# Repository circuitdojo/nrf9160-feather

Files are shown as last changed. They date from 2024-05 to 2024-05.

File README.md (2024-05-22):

# Circuit Dojo - nRF9160 Feather Hardware Files

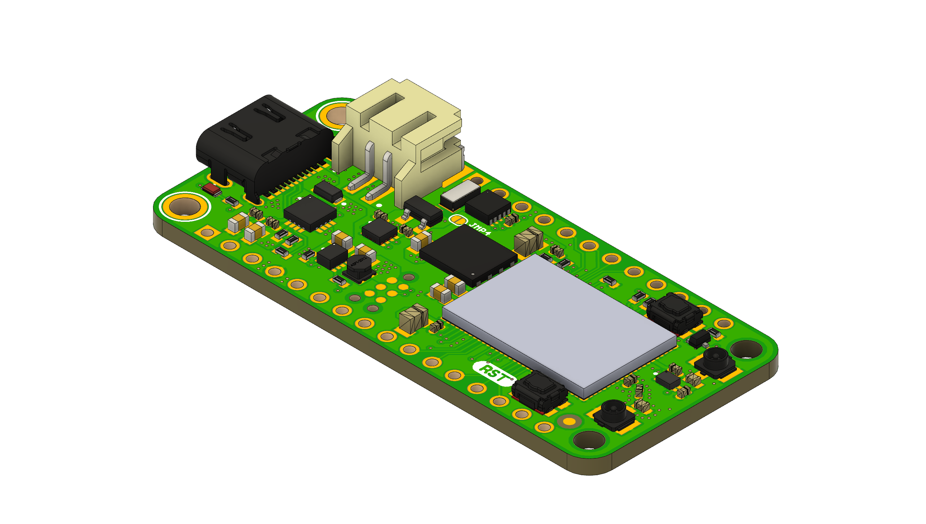
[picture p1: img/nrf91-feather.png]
nRF9160 Feather


## Purchase

Considering supporting the project and purchasing a nRF9160 Feather at the following locations:

1. [The Circuit Dojo Official Store](https://www.circuitdojo.com/products/nrf9160-feather)
2. [Digikey](https://www.digikey.com/en/products/detail/circuit-dojo/PASSY-NRF9160-FEATHER/13668137)

## Code

All code for this board can be [found here.](https://github.com/circuitdojo/nrf9160-feather-examples-and-drivers/tree/v1.9.x)

## Documentation

[Documentation is available here.](https://docs.circuitdojo.com)

## License

Hardware released under the CERN Open Hardware Licence Version 2 - Weakly Reciprocal. See **LICENSE.txt** for more info.

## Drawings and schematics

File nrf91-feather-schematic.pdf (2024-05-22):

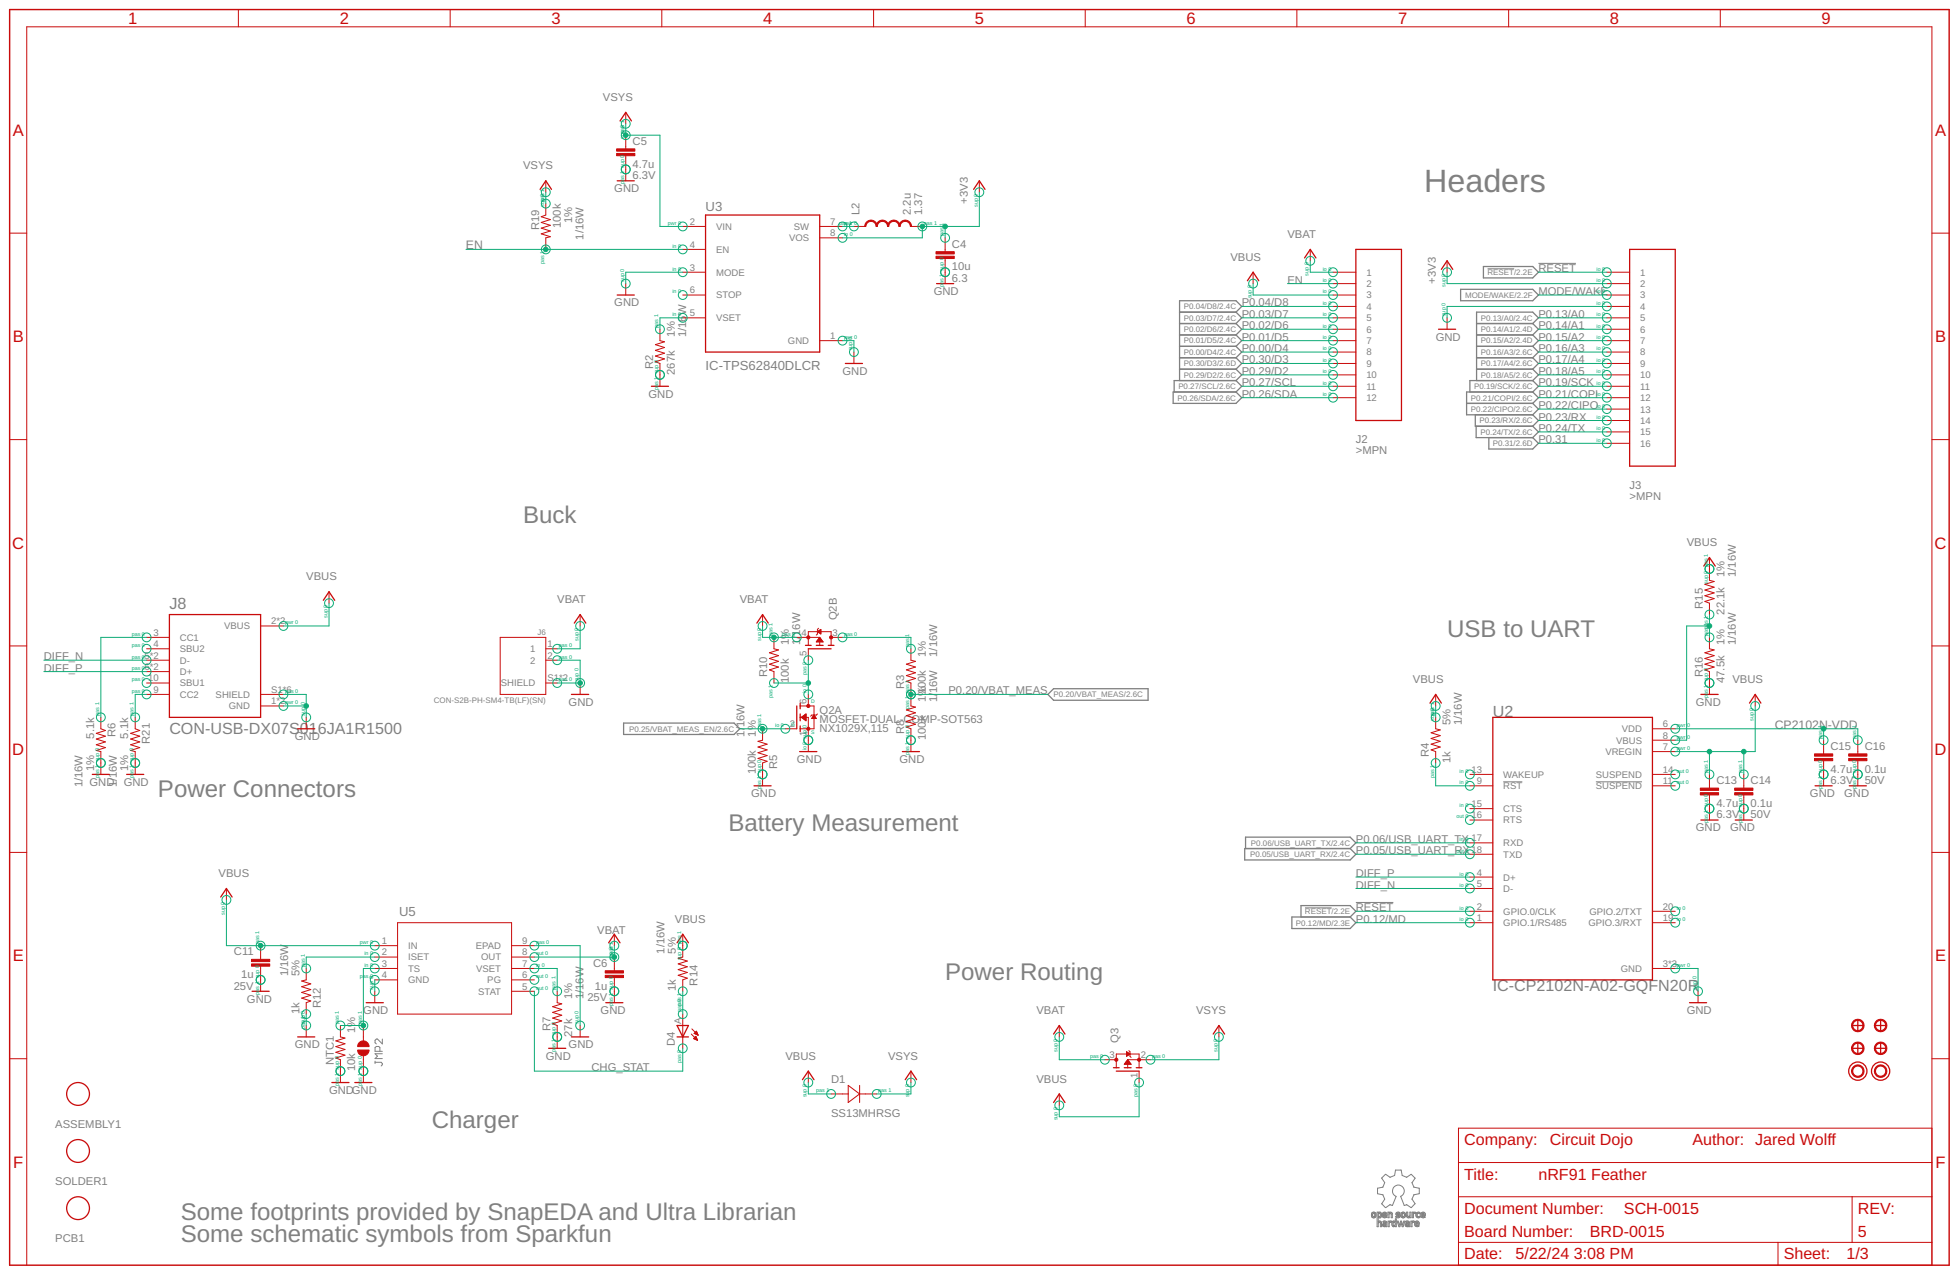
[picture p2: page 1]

sup 0
MODE/WAKE/2.2F MODE/WAKE

sup 0 pas 1 pas 1 pas 1 pas 1 sup 0

pas 1 pas 1 pas 1 pas 1 sup 0

in 0 | 8 EPAD 7 OUT out 0

pas 1 pas 1 pas 0 pas 0

in 0 | 6 VSET in 0

Some footprints provided by SnapEDA and Ultra Librarian
Some schematic symbols from Sparkfun

SCH-0015

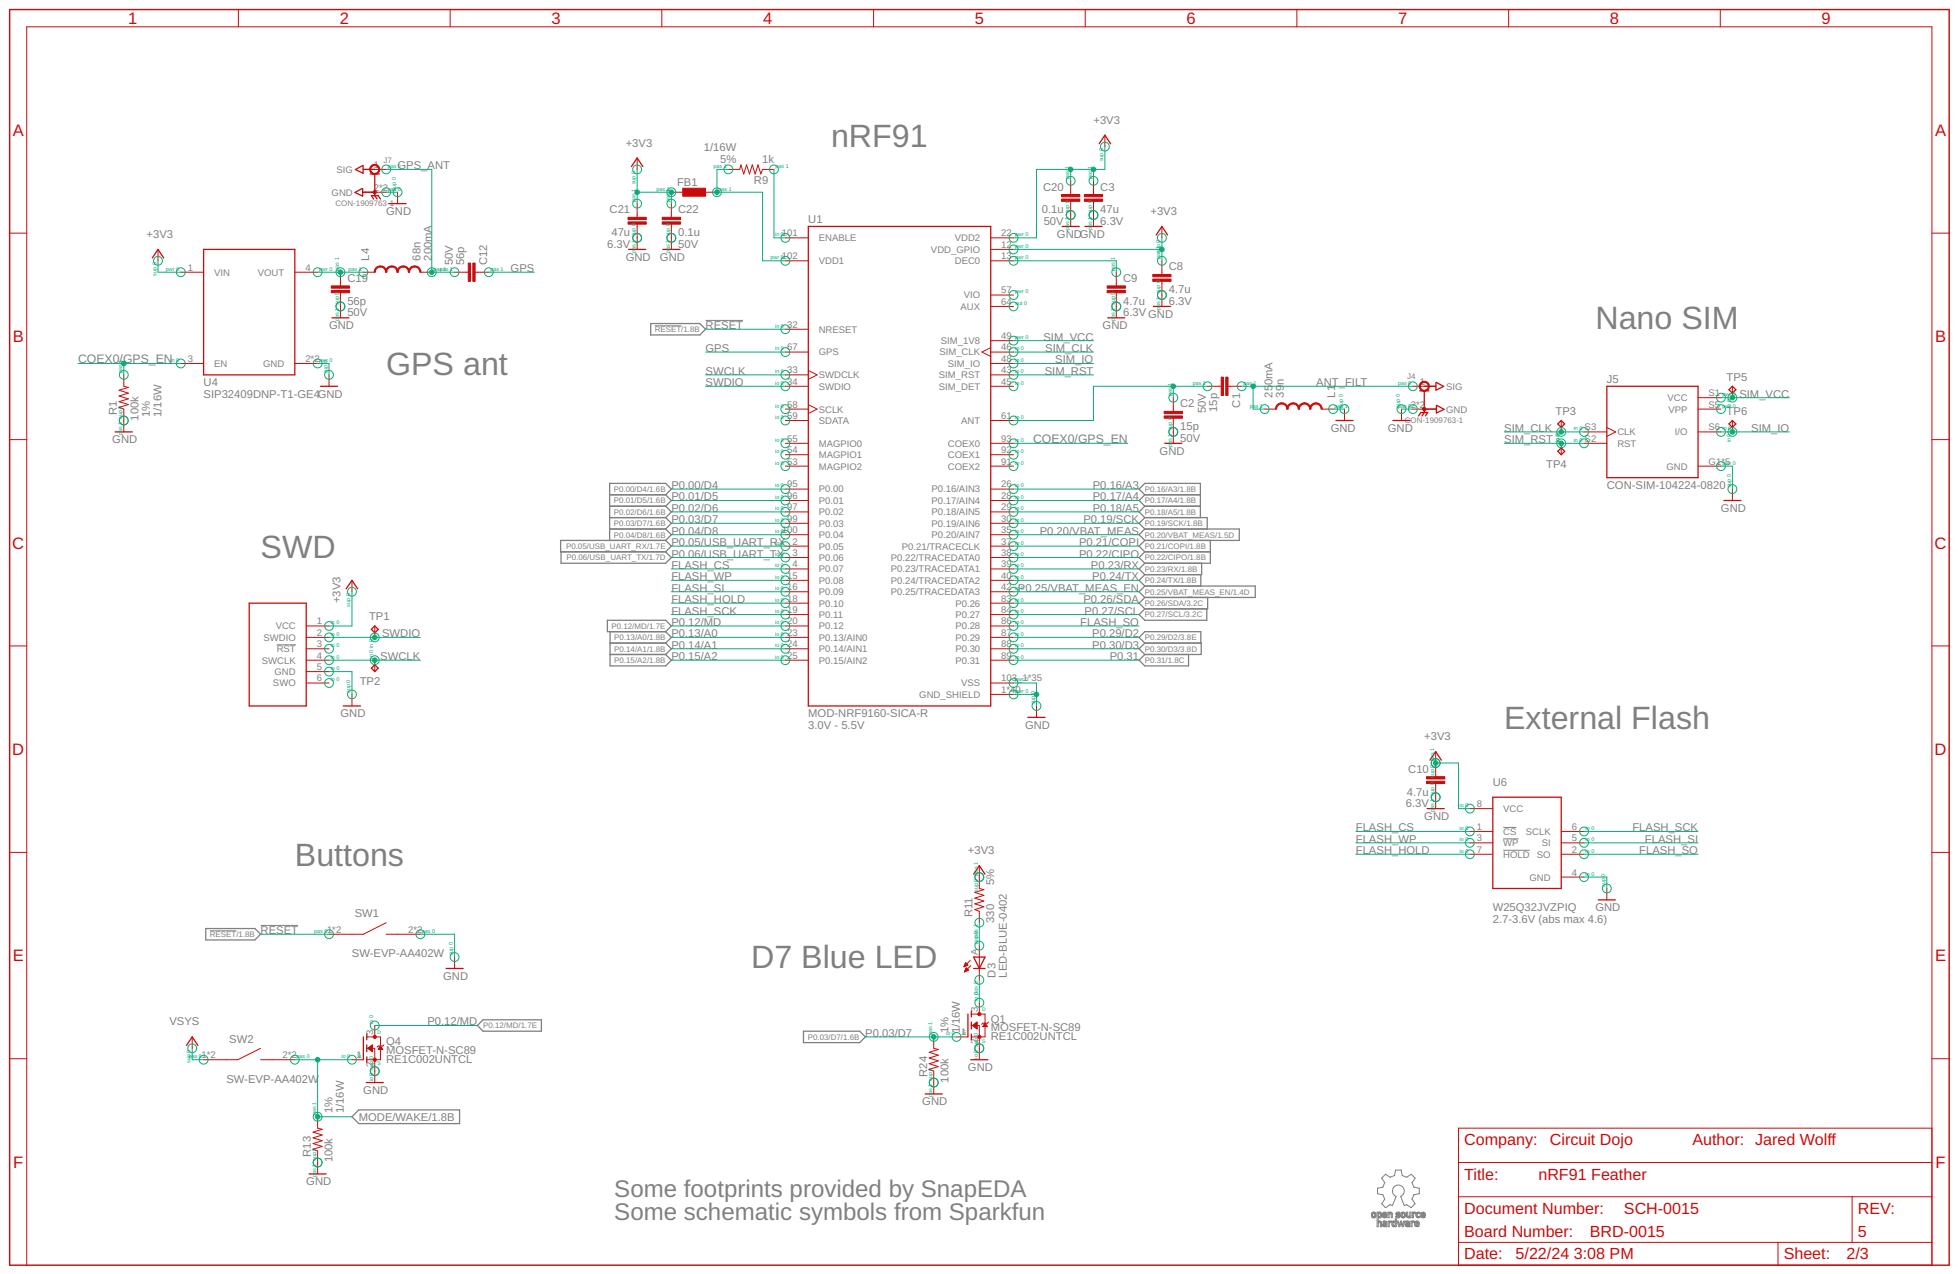
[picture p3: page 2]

sup 0 pas 1 pas 1 sup 0

Some footprints provided by SnapEDA
Some schematic symbols from Sparkfun

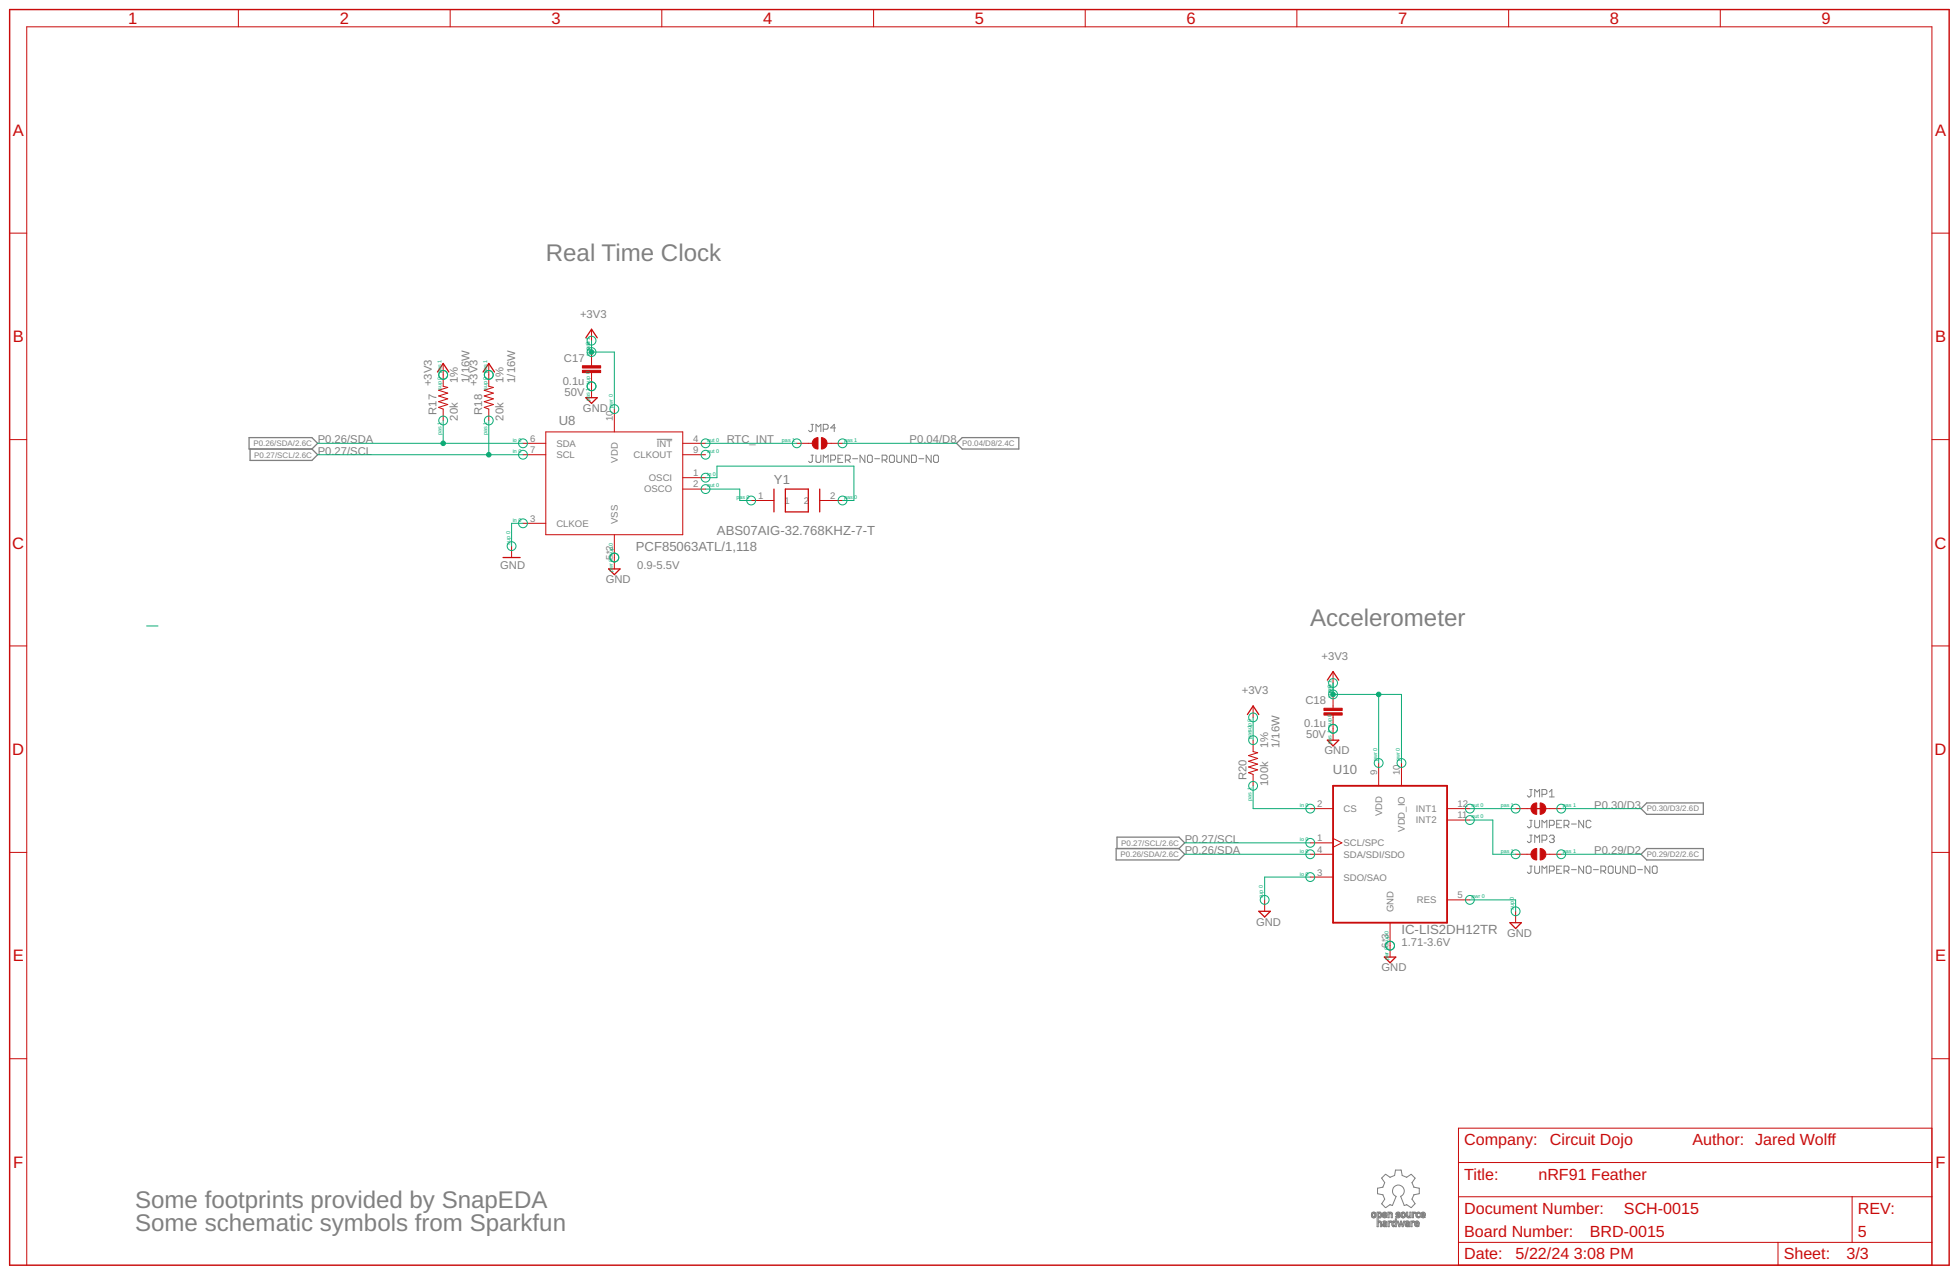
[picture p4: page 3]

pas 1 pas 1 sup 0 sup 0

Some footprints provided by SnapEDA
Some schematic symbols from Sparkfun

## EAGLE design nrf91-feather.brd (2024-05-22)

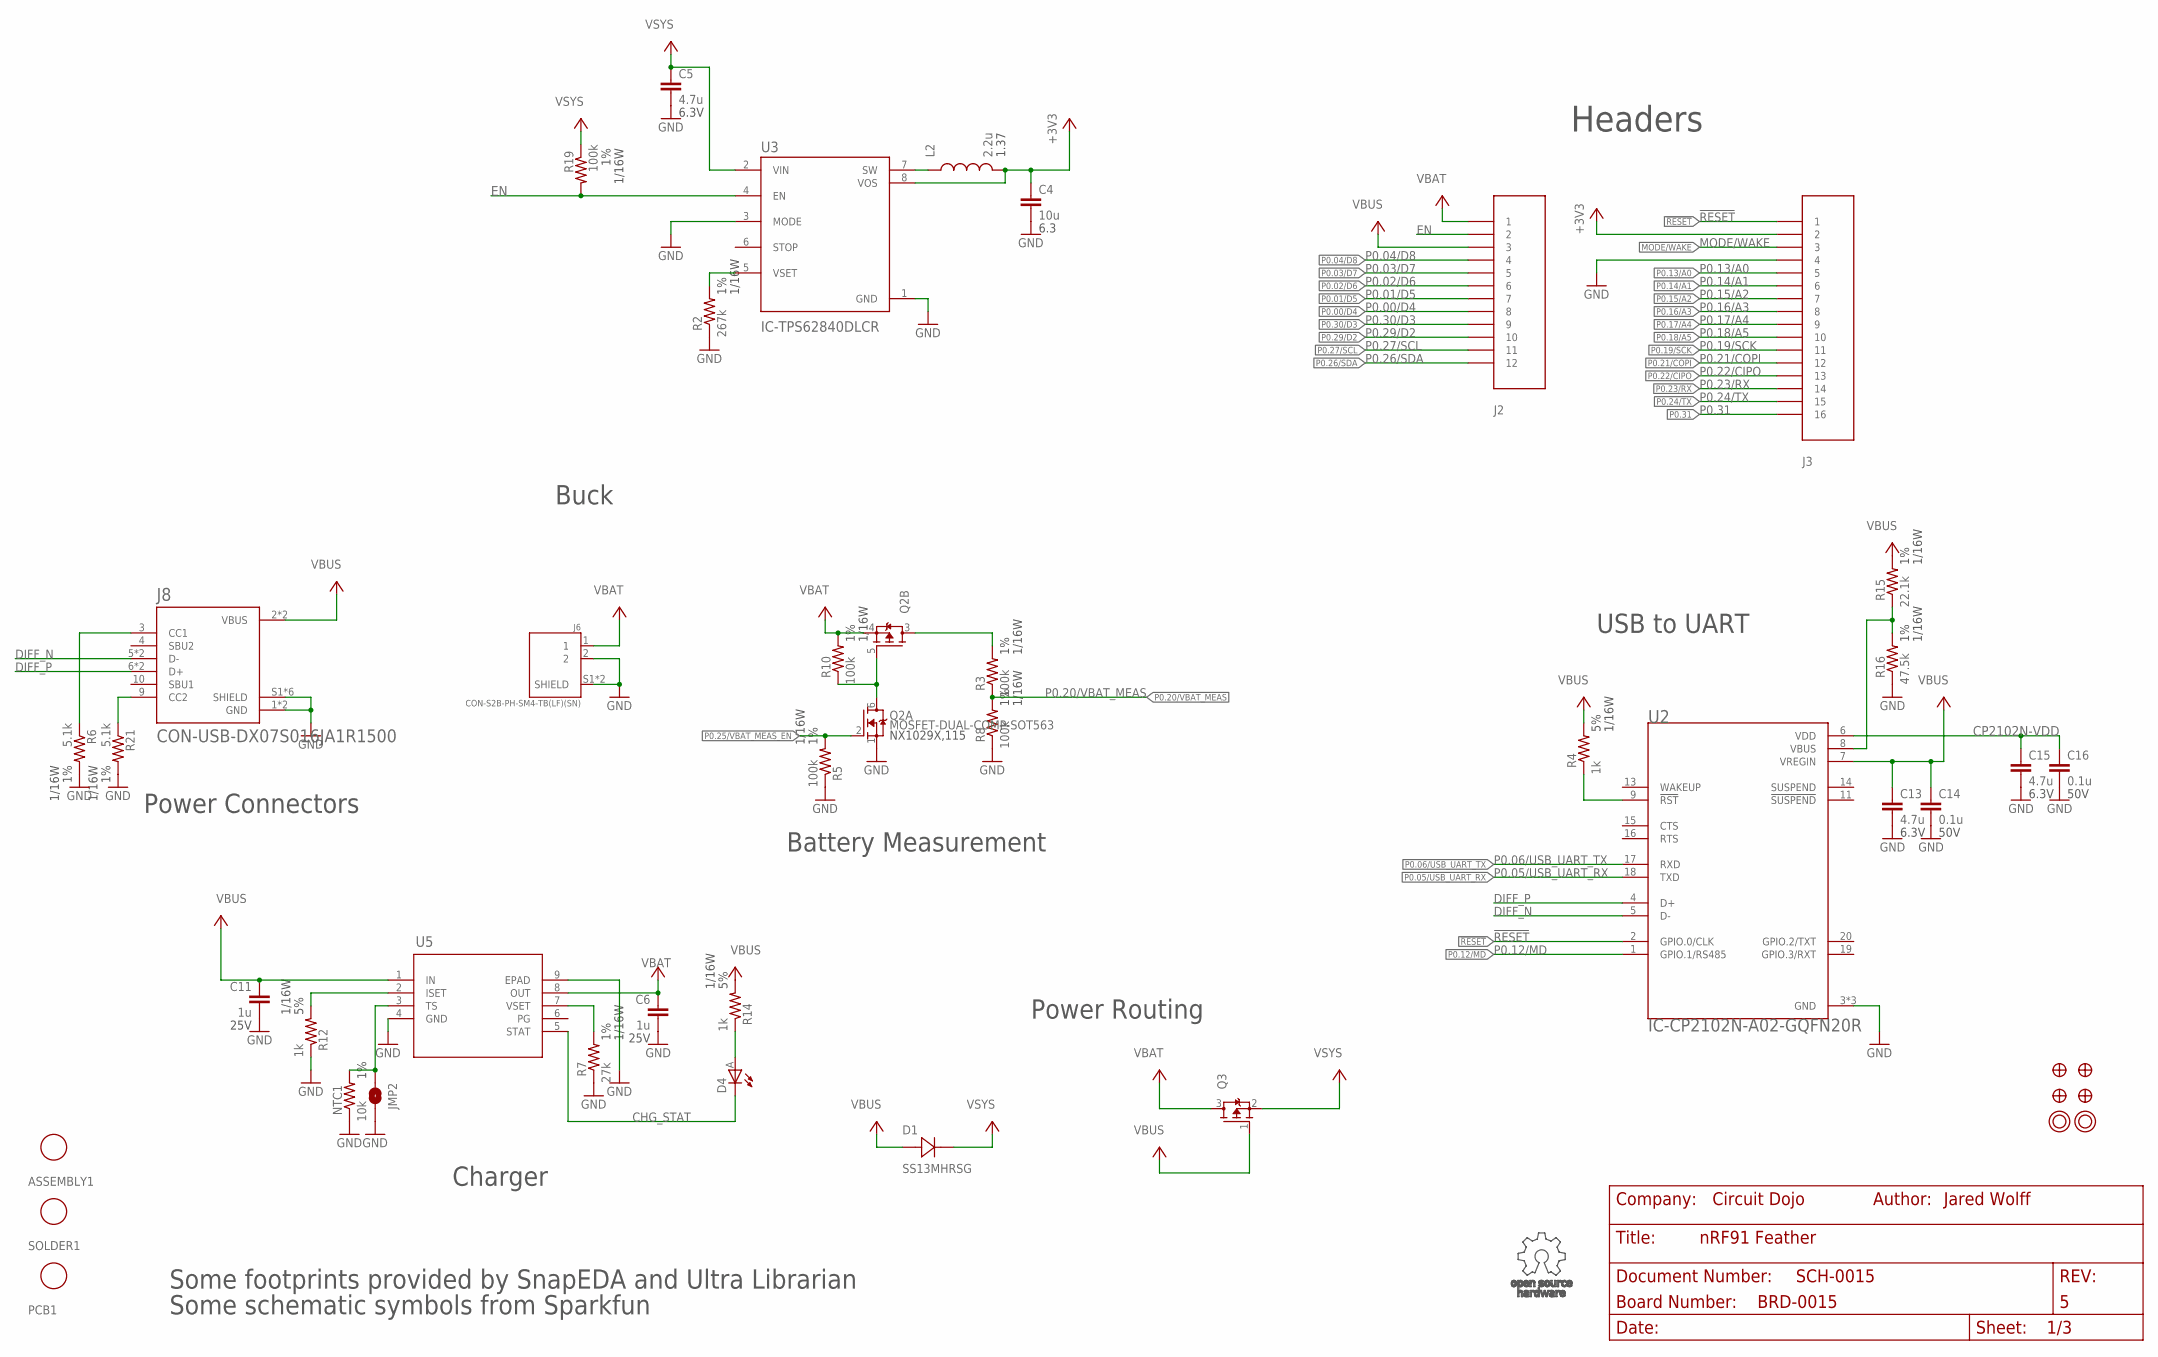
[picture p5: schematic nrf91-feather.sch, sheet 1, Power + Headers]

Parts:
ASSEMBLY1: ASSY-COST-NRF91-FEATHER; PLACEHOLDER
C4: 10u; C0603
C5, C13, C15: 4.7u; C0603
C6, C11: 1u; CAPC1005X55N
C14, C16: 0.1u; CAPC1005X55N
D1: DIO-SCHOTTKY-1A-SMA-MICRO; SMA-MICRO
D4: LED-ORANGE-0402; LED_EAST1005
J2: CON-HEADER-1X12-MALE-PIN
J3: CON-HEADER-1X16-MALE-PIN
J6: CON-S2B-PH-SM4-TB(LF)(SN); JST_S2B-PH-SM4-TB(LF)(SN)
J8: CON-USB-DX07S016JA1R1500; JAE_DX07S016JA1R1500
JMP2: JUMPER-NO-ROUND-NO; JUMPER-ROUND-N0
L2: 2.2u; IND-2P0X2P0X1P2
NTC1: 10k; R0402-M
PCB1: PCB-NRF91-FEATHER; PLACEHOLDER
Q2: MOSFET-DUAL-COMP-SOT563; SOT50P160X60-6N
Q3: MOSFET-P-20V-4.7A-SOT23; SOT23
R2: 267k; R0402-M
R3, R5, R8, R10, R19: 100k; R0402-M
R4, R12, R14: 1k; R0402-M
R6, R21: 5.1k; R0402-M
R7: 27k; R0402-M
R15: 22.1k; R0402-M
R16: 47.5k; R0402-M
SOLDER1: SOLDER-PASTE-ROOM-TEMP-50G; PLACEHOLDER
U2: IC-CP2102N-A02-GQFN20R; SILABS_CP2102N-A02-GQFN20R
U3: IC-TPS62840DLCR; SON50P200X150X100-8N
U5: IC-BQ25170JDSGR-WSON8; WSON8_BQ2517_TEX-L
U$3, U$4, U$34, U$35: FIDUCIAL-1MM
U$31, U$32: MOUNTING-HOLE-2.5MM-PLATED

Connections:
!RESET: J3.1, U2.2 (GPIO.0/CLK); also elsewhere on the board
+3V3: C4.1, J3.2, L2.P$2 (2), U3.8 (VOS); also elsewhere on the board
CHG_ISET: R12.2, U5.2 (ISET)
CHG_STAT: D4.C, U5.5 (STAT)
CHG_TS: JMP2.P$1 (1), NTC1.2, U5.3 (TS)
CHG_VSET: R7.2, U5.7 (VSET)
CP2102N-!RST: R4.1, U2.9 (!RST)
CP2102N-VDD: C15.1, C16.1, U2.6 (VDD)
DIFF_N: J8.5 (D-), J8.8 (D-), U2.5 (D-)
DIFF_P: J8.6 (D+), J8.7 (D+), U2.4 (D+)
EN: J2.2, R19.2, U3.4 (EN)
GND: C4.2, C5.2, C6.2, C11.2, C13.2, C14.2, C15.2, C16.2, J3.4, J6.2, J6.S1 (SHIELD), J6.S2 (SHIELD), J8.1 (GND), J8.12 (GND), J8.S1 (SHIELD), J8.S2 (SHIELD), J8.S3 (SHIELD), J8.S4 (SHIELD), J8.S5 (SHIELD), J8.S6 (SHIELD), JMP2.P$2 (2), NTC1.1, Q2.1 (S), R2.1, R5.1, R6.2, R7.1, R8.1, R12.1, R16.1, R21.2, U2.3 (GND), U2.12 (GND), U2.21 (GND), U3.1 (GND), U3.3 (MODE), U5.4 (GND), U5.9 (EPAD); also elsewhere on the board
MODE/WAKE: J3.3; also elsewhere on the board
unnamed: R2.2, U3.5 (VSET)
unnamed: L2.P$1 (1), U3.7 (SW)
unnamed: Q2.3 (D), R3.2
unnamed: Q2.5 (G), Q2.6 (D), R10.1
unnamed: R15.1, R16.2, U2.8 (VBUS)
unnamed: D4.A, R14.1
P0.00/D4: J2.8; also elsewhere on the board
P0.01/D5: J2.7; also elsewhere on the board
P0.02/D6: J2.6; also elsewhere on the board
P0.03/D7: J2.5; also elsewhere on the board
P0.04/D8: J2.4; also elsewhere on the board
P0.05/USB_UART_RX: U2.18 (TXD); also elsewhere on the board
P0.06/USB_UART_TX: U2.17 (RXD); also elsewhere on the board
P0.12/MD: U2.1 (GPIO.1/RS485); also elsewhere on the board
P0.13/A0: J3.5; also elsewhere on the board
P0.14/A1: J3.6; also elsewhere on the board
P0.15/A2: J3.7; also elsewhere on the board
P0.16/A3: J3.8; also elsewhere on the board
P0.17/A4: J3.9; also elsewhere on the board
P0.18/A5: J3.10; also elsewhere on the board
P0.19/SCK: J3.11; also elsewhere on the board
P0.20/VBAT_MEAS: R3.1, R8.2; also elsewhere on the board
P0.21/COPI: J3.12; also elsewhere on the board
P0.22/CIPO: J3.13; also elsewhere on the board
P0.23/RX: J3.14; also elsewhere on the board
P0.24/TX: J3.15; also elsewhere on the board
P0.25/VBAT_MEAS_EN: Q2.2 (G), R5.2; also elsewhere on the board
P0.26/SDA: J2.12; also elsewhere on the board
P0.27/SCL: J2.11; also elsewhere on the board
P0.29/D2: J2.10; also elsewhere on the board
P0.30/D3: J2.9; also elsewhere on the board
P0.31: J3.16; also elsewhere on the board
USB_CC1: J8.3 (CC1), R6.1
USB_CC2: J8.9 (CC2), R21.1
VBAT: C6.1, J2.1, J6.1, Q2.4 (S), Q3.3 (D), R10.2, U5.8 (OUT)
VBUS: C11.1, C13.1, C14.1, D1.2 (1), J2.3, J8.2 (VBUS), J8.11 (VBUS), Q3.1 (G), R4.2, R14.2, R15.2, U2.7 (VREGIN), U5.1 (IN)
VSYS: C5.1, D1.1 (2), Q3.2 (S), R19.1, U3.2 (VIN); also elsewhere on the board

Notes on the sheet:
Headers
Some footprints provided by SnapEDA and Ultra Librarian
Buck
Power Routing
Battery Measurement
Charger
USB to UART
Power Connectors
Some schematic symbols from Sparkfun

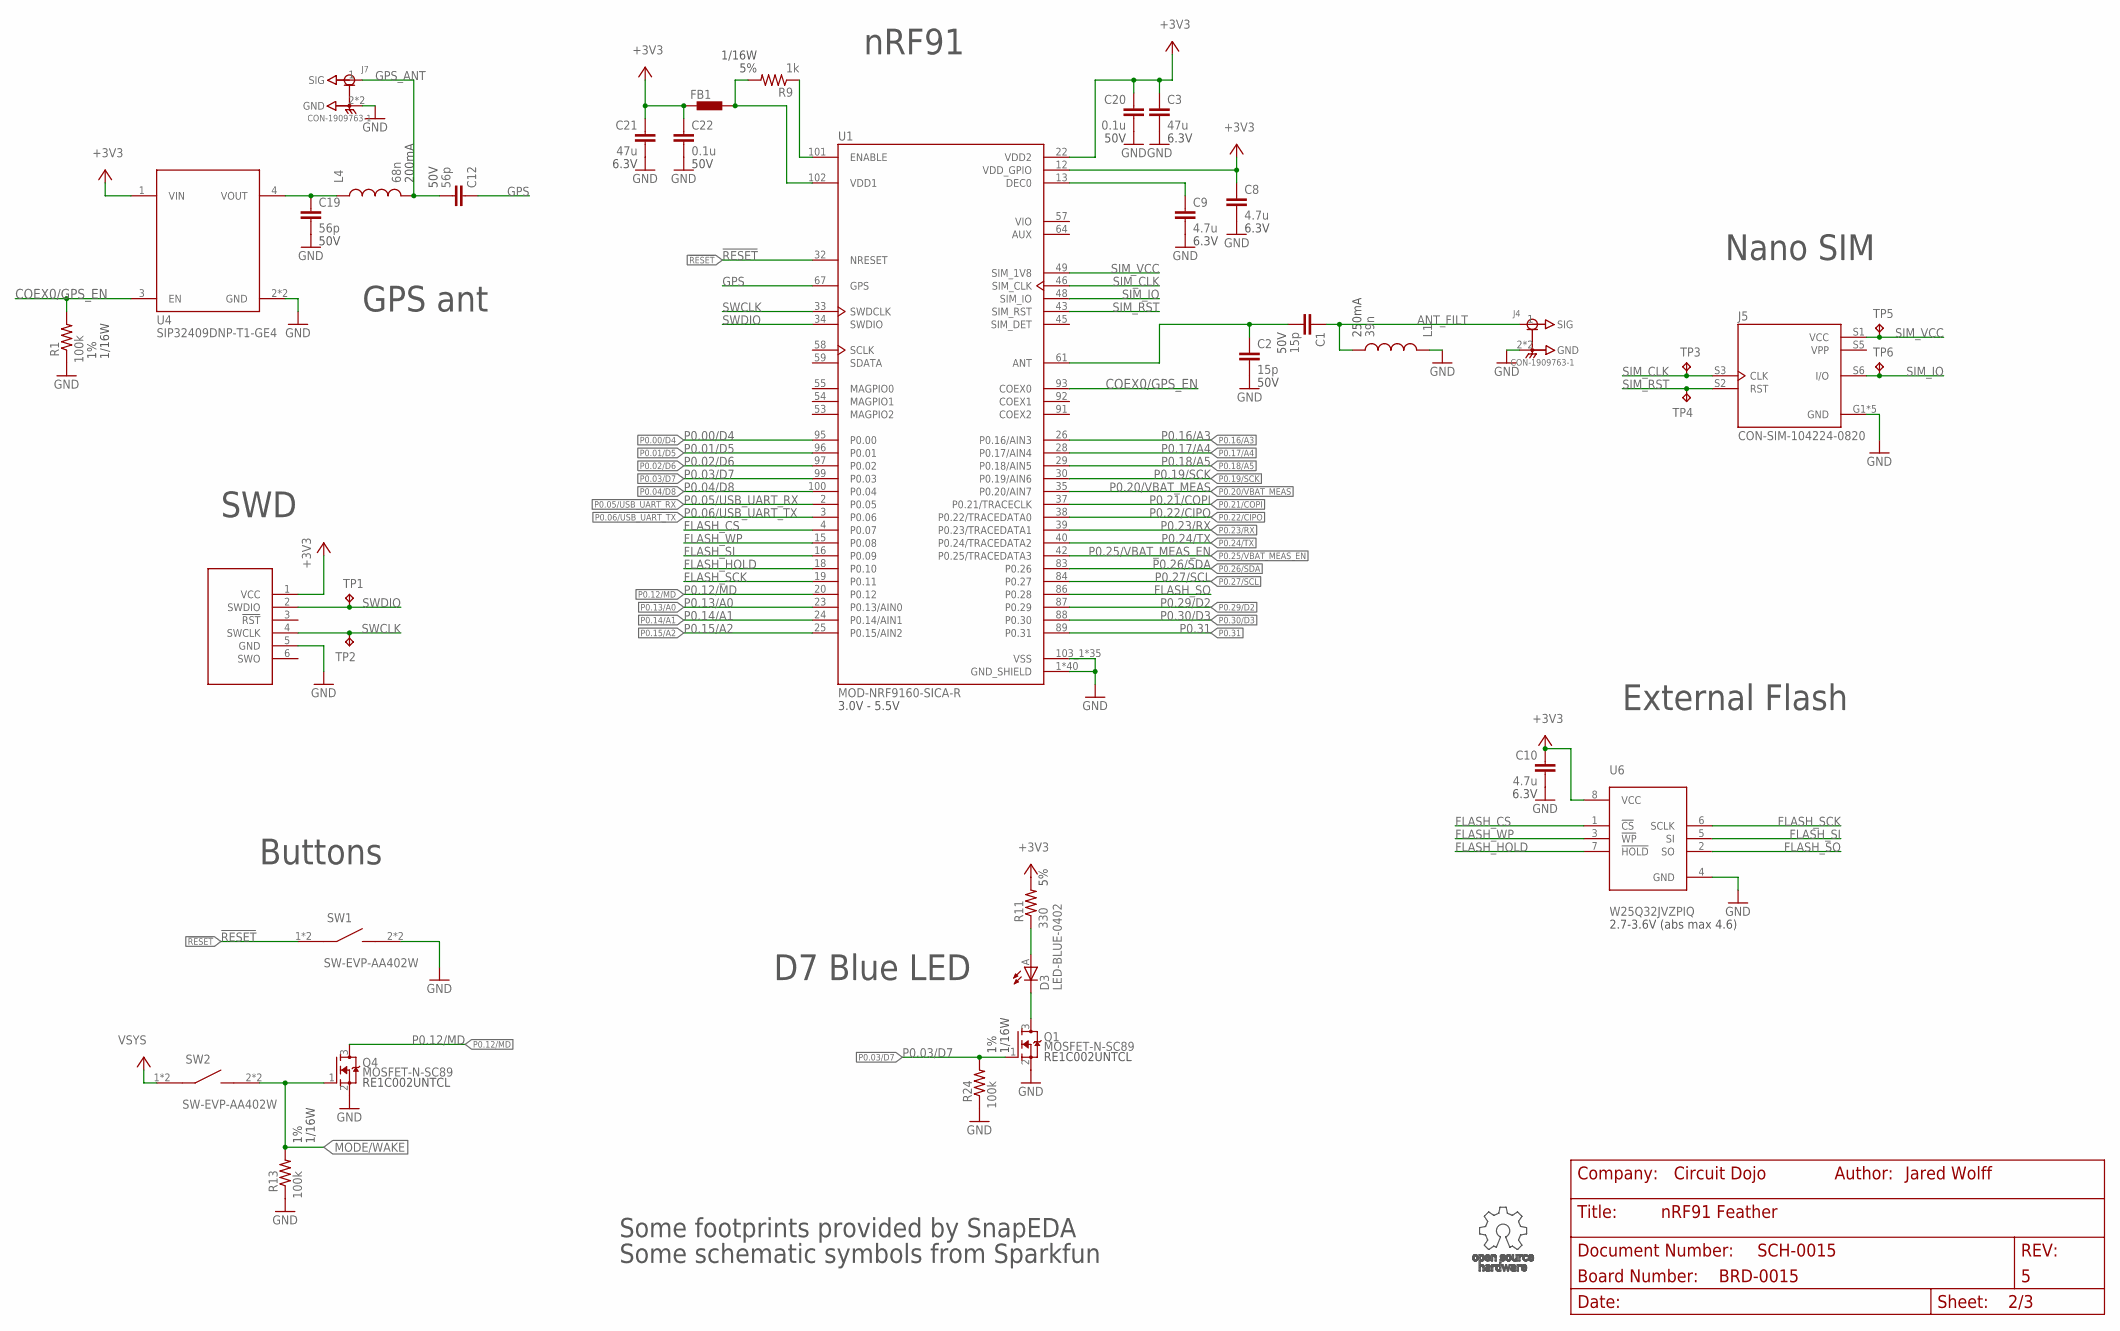
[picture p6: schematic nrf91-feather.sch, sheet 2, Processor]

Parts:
C1, C2: 15p; CAPC1005X55N
C3, C21: 47u; C0805
C8, C9, C10: 4.7u; C0603
C12, C19: 56p; CAPC1005X55N
C20, C22: 0.1u; CAPC1005X55N
D3: LED-BLUE-0402; LED_EAST1005
FB1: FERRITE-120-100MHZ-0402; R0402-M
J4, J7: CON-1909763-1; TE_1909763-1
J5: CON-SIM-104224-0820; MOLEX_104224-0820
J9: CON-TC2030-MCP-NL; TC2030-MCP-NL
L1: 39n; IND0402_22N_TAI
L4: 68n; IND0402_22N_TAI
Q1, Q4: MOSFET-N-SC89; DIO_RB558WMF-L
R1, R13, R24: 100k; R0402-M
R9: 1k; R0402-M
R11: 330; R0402-M
SW1, SW2: SW-EVP-AA402W
TP1, TP2, TP3, TP4, TP5, TP6: TP-1SIDE-1P0; TP-1P0
U1: MOD-NRF9160-SICA-R; NORDIC_NRF9160-SICA-R
U4: POWER-SWITCH-SIP32409-DFN4; SON50P160X120X60-5N
U6: FLASH-W25Q32JVZPIQ-WSON; WIN_ZP-8-L

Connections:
!RESET: SW1.1, SW1.3 (1), U1.32 (NRESET); also elsewhere on the board
+3V3: C3.1, C8.1, C10.1, C20.1, C21.1, C22.1, FB1.1, J9.1 (VCC), R11.2, U1.12 (VDD_GPIO), U1.22 (VDD2), U4.1 (VIN), U6.8 (VCC); also elsewhere on the board
ANT: C1.2, C2.1, U1.61 (ANT)
ANT_FILT: C1.1, J4.1 (SIG), L1.2
COEX0/GPS_EN: R1.2, U1.93 (COEX0), U4.3 (EN)
FLASH_CS: U1.4 (P0.07), U6.1 (!CS)
FLASH_HOLD: U1.18 (P0.10), U6.7 (!HOLD)
FLASH_SCK: U1.19 (P0.11), U6.6 (SCLK)
FLASH_SI: U1.16 (P0.09), U6.5 (SI)
FLASH_SO: U1.86 (P0.28), U6.2 (SO)
FLASH_WP: U1.15 (P0.08), U6.3 (!WP)
GND: C2.2, C3.2, C8.2, C9.2, C10.2, C19.2, C20.2, C21.2, C22.2, J4.2 (GND), J4.3 (GND), J5.G1 (GND), J5.G2 (GND), J5.G3 (GND), J5.G4 (GND), J5.S4 (GND), J7.2 (GND), J7.3 (GND), J9.5 (GND), L1.1, Q1.2 (S), Q4.2 (S), R1.1, R13.1, R24.1, SW1.2, SW1.4 (2), U1.1 (GND_SHIELD), U1.5 (GND_SHIELD), U1.6 (GND_SHIELD), U1.7 (GND_SHIELD), U1.8 (GND_SHIELD), U1.9 (GND_SHIELD), U1.11 (GND_SHIELD), U1.14 (GND_SHIELD), U1.17 (GND_SHIELD), U1.21 (GND_SHIELD), U1.27 (GND_SHIELD), U1.31 (GND_SHIELD), U1.36 (GND_SHIELD), U1.41 (GND_SHIELD), U1.44 (GND_SHIELD), U1.47 (GND_SHIELD), U1.50 (GND_SHIELD), U1.52 (GND_SHIELD), U1.56 (GND_SHIELD), U1.60 (GND_SHIELD), U1.62 (GND_SHIELD), U1.63 (GND_SHIELD), U1.65 (GND_SHIELD), U1.66 (GND_SHIELD), U1.68 (GND_SHIELD), U1.69 (GND_SHIELD), U1.72 (GND_SHIELD), U1.74 (GND_SHIELD), U1.75 (GND_SHIELD), U1.76 (GND_SHIELD), U1.77 (GND_SHIELD), U1.78 (GND_SHIELD), U1.79 (GND_SHIELD), U1.80 (GND_SHIELD), U1.81 (GND_SHIELD), U1.82 (GND_SHIELD), U1.85 (GND_SHIELD), U1.90 (GND_SHIELD), U1.94 (GND_SHIELD), U1.98 (GND_SHIELD), U1.103_1 (VSS), U1.103_2 (VSS), U1.103_3 (VSS), U1.103_4 (VSS), U1.103_5 (VSS), U1.103_6 (VSS), U1.103_7 (VSS), U1.103_8 (VSS), U1.103_9 (VSS), U1.103_10 (VSS), U1.103_11 (VSS), U1.103_12 (VSS), U1.103_13 (VSS), U1.103_14 (VSS), U1.103_15 (VSS), U1.103_16 (VSS), U1.103_17 (VSS), U1.103_18 (VSS), U1.103_19 (VSS), U1.103_20 (VSS), U1.103_21 (VSS), U1.103_22 (VSS), U1.103_23 (VSS), U1.103_24 (VSS), U1.103_25 (VSS), U1.103_26 (VSS), U1.103_27 (VSS), U1.103_28 (VSS), U1.103_29 (VSS), U1.103_30 (VSS), U1.103_31 (VSS), U1.103_32 (VSS), U1.103_33 (VSS), U1.103_34 (VSS), U1.103_35 (VSS), U4.2 (GND), U4.5 (GND), U6.4 (GND); also elsewhere on the board
GPS: C12.1, U1.67 (GPS)
GPS_ANT: C12.2, J7.1 (SIG), L4.2
LNA_SW_OUT: C19.1, L4.1, U4.4 (VOUT)
MODE/WAKE: Q4.1 (G), R13.2, SW2.2, SW2.4 (2); also elsewhere on the board
unnamed: R9.1, U1.101 (ENABLE)
unnamed: C9.1, U1.13 (DEC0)
unnamed: D3.A, R11.1
unnamed: D3.C, Q1.3 (D)
unnamed: FB1.2, R9.2, U1.102 (VDD1)
P0.00/D4: U1.95 (P0.00); also elsewhere on the board
P0.01/D5: U1.96 (P0.01); also elsewhere on the board
P0.02/D6: U1.97 (P0.02); also elsewhere on the board
P0.03/D7: Q1.1 (G), R24.2, U1.99 (P0.03); also elsewhere on the board
P0.04/D8: U1.100 (P0.04); also elsewhere on the board
P0.05/USB_UART_RX: U1.2 (P0.05); also elsewhere on the board
P0.06/USB_UART_TX: U1.3 (P0.06); also elsewhere on the board
P0.12/MD: Q4.3 (D), U1.20 (P0.12); also elsewhere on the board
P0.13/A0: U1.23 (P0.13/AIN0); also elsewhere on the board
P0.14/A1: U1.24 (P0.14/AIN1); also elsewhere on the board
P0.15/A2: U1.25 (P0.15/AIN2); also elsewhere on the board
P0.16/A3: U1.26 (P0.16/AIN3); also elsewhere on the board
P0.17/A4: U1.28 (P0.17/AIN4); also elsewhere on the board
P0.18/A5: U1.29 (P0.18/AIN5); also elsewhere on the board
P0.19/SCK: U1.30 (P0.19/AIN6); also elsewhere on the board
P0.20/VBAT_MEAS: U1.35 (P0.20/AIN7); also elsewhere on the board
P0.21/COPI: U1.37 (P0.21/TRACECLK); also elsewhere on the board
P0.22/CIPO: U1.38 (P0.22/TRACEDATA0); also elsewhere on the board
P0.23/RX: U1.39 (P0.23/TRACEDATA1); also elsewhere on the board
P0.24/TX: U1.40 (P0.24/TRACEDATA2); also elsewhere on the board
P0.25/VBAT_MEAS_EN: U1.42 (P0.25/TRACEDATA3); also elsewhere on the board
P0.26/SDA: U1.83 (P0.26); also elsewhere on the board
P0.27/SCL: U1.84 (P0.27); also elsewhere on the board
P0.29/D2: U1.87 (P0.29); also elsewhere on the board
P0.30/D3: U1.88 (P0.30); also elsewhere on the board
P0.31: U1.89 (P0.31); also elsewhere on the board
SIM_CLK: J5.S3 (CLK), TP3.TP, U1.46 (SIM_CLK)
SIM_IO: J5.S6 (I/O), TP6.TP, U1.48 (SIM_IO)
SIM_RST: J5.S2 (RST), TP4.TP, U1.43 (SIM_RST)
SIM_VCC: J5.S1 (VCC), TP5.TP, U1.49 (SIM_1V8)
SWCLK: J9.4 (SWCLK), TP2.TP, U1.33 (SWDCLK)
SWDIO: J9.2 (SWDIO), TP1.TP, U1.34 (SWDIO)
VIO: U1.57 (VIO)
VPP: J5.S5 (VPP)
VSYS: SW2.1, SW2.3 (1); also elsewhere on the board

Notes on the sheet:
nRF91
Nano SIM
SWD
Buttons
External Flash
D7 Blue LED
3.0V - 5.5V
2.7-3.6V (abs max 4.6)
GPS ant
Some footprints provided by SnapEDA
Some schematic symbols from Sparkfun

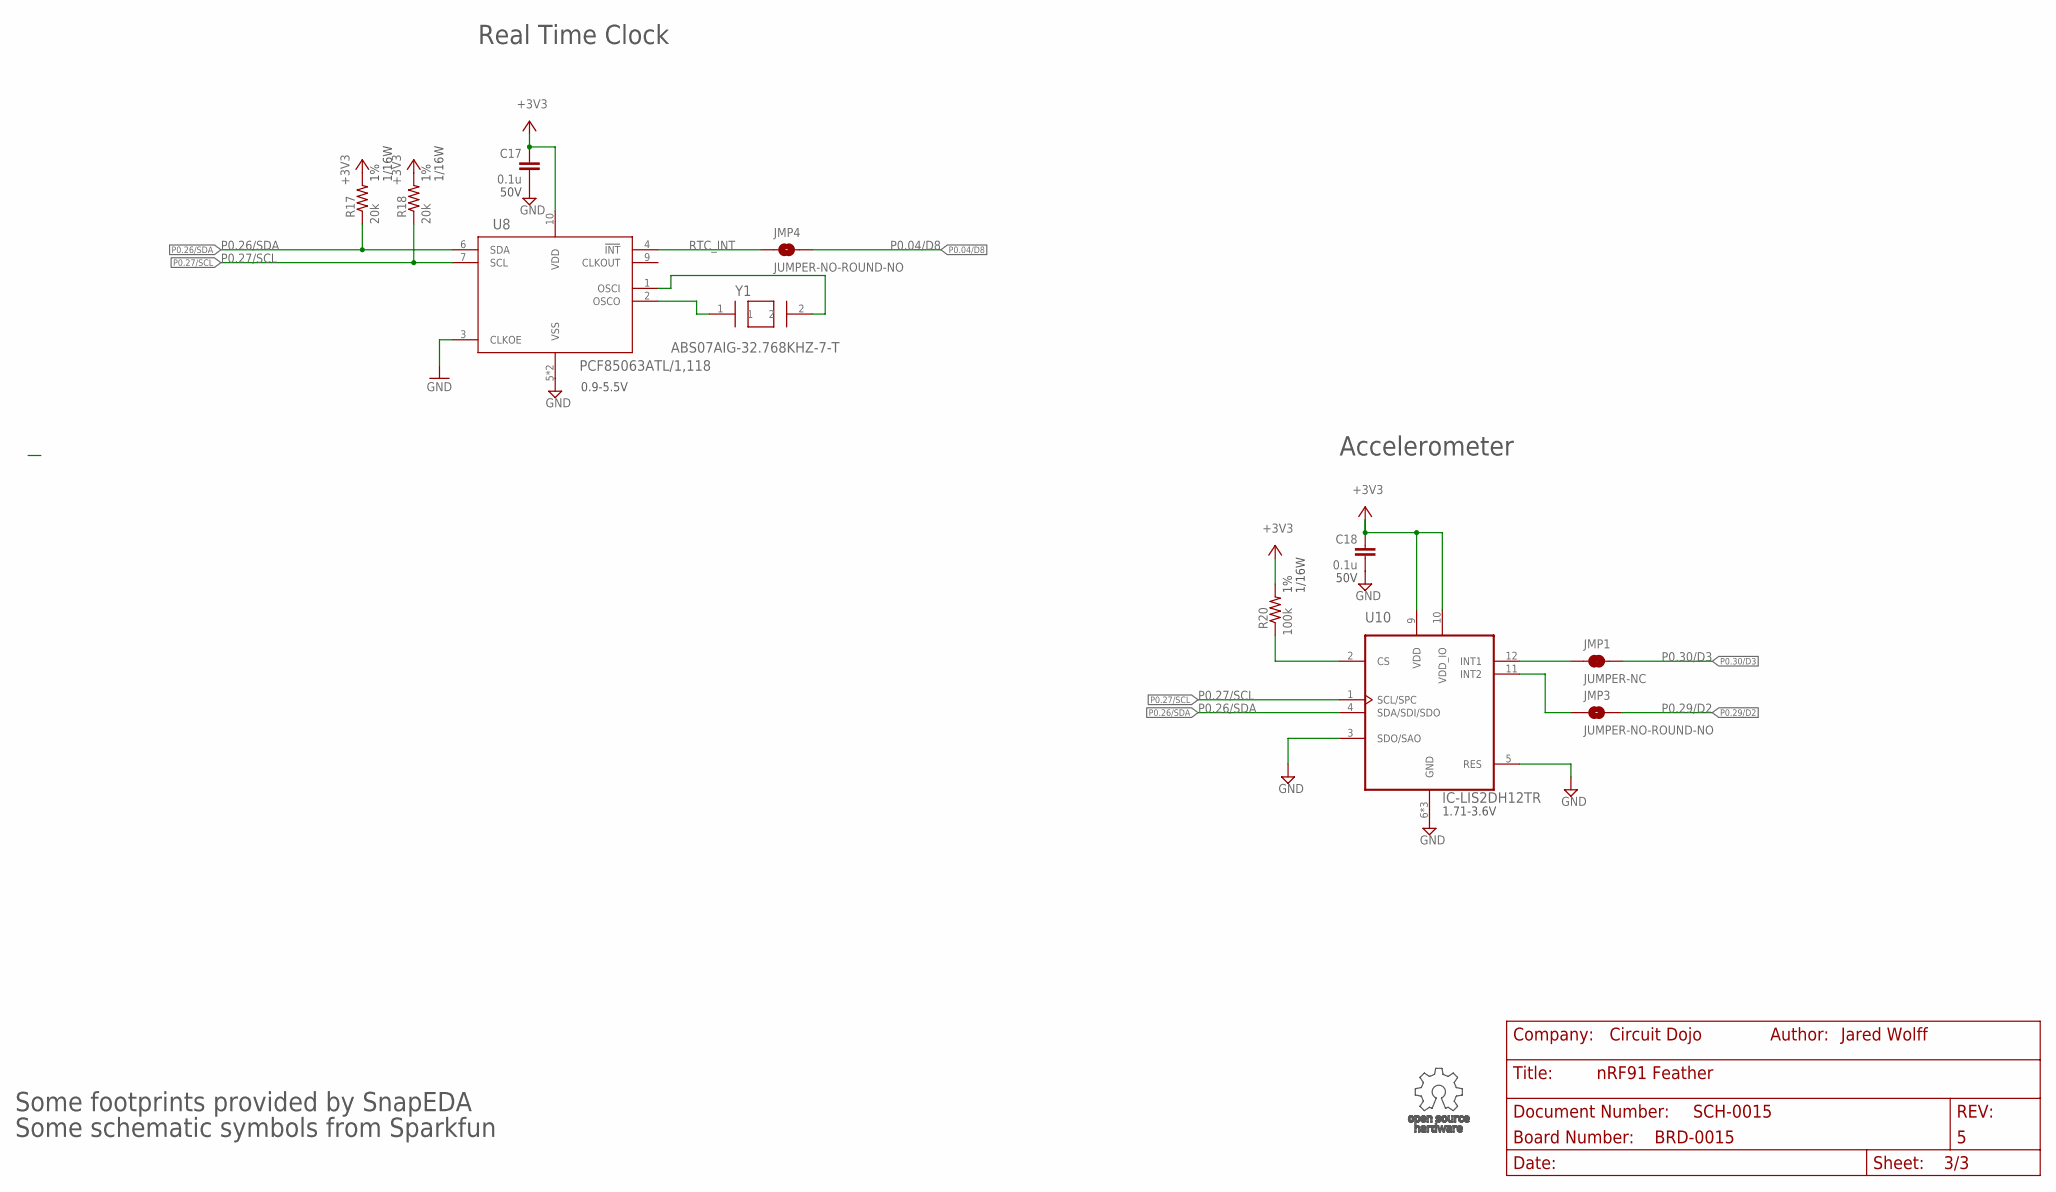
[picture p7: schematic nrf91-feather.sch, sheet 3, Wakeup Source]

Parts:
C17, C18: 0.1u; CAPC1005X55N
JMP1: JUMPER-NC; JUMPER-ROUND-NC
JMP3, JMP4: JUMPER-NO-ROUND-NO; JUMPER-ROUND-N0
R17, R18: 20k; R0402-M
R20: 100k; R0402-M
U8: IC-PCF85063ATL/1; DFN10_2P7X2P7-L
U10: IC-LIS2DH12TR; PQFN50P200X200100-12N
Y1: XTAL-ABS07AIG-32.768KHZ-7-T; XTAL320X150X90

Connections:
+3V3: C17.1, C18.1, R17.2, R18.2, R20.2, U8.10 (VDD), U10.9 (VDD), U10.10 (VDD_IO); also elsewhere on the board
GND: C17.2, C18.2, U8.3 (CLKOE), U8.5 (VSS), U8.11 (VSS), U10.3 (SDO/SAO), U10.5 (RES), U10.6 (GND), U10.7 (GND), U10.8 (GND); also elsewhere on the board
LIS2DH_INT1: JMP1.P$1 (1), U10.12 (INT1)
LIS2DH_INT2: JMP3.P$1 (1), U10.11 (INT2)
unnamed: R20.1, U10.2 (CS)
unnamed: U8.1 (OSCI), Y1.2
unnamed: U8.2 (OSCO), Y1.1
P0.04/D8: JMP4.P$2 (2); also elsewhere on the board
P0.26/SDA: R17.1, U8.6 (SDA), U10.4 (SDA/SDI/SDO); also elsewhere on the board
P0.27/SCL: R18.1, U8.7 (SCL), U10.1 (SCL/SPC); also elsewhere on the board
P0.29/D2: JMP3.P$2 (2); also elsewhere on the board
P0.30/D3: JMP1.P$2 (2); also elsewhere on the board
RTC_INT: JMP4.P$1 (1), U8.4 (!INT)

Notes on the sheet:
Real Time Clock
0.9-5.5V
Accelerometer
1.71-3.6V
Some footprints provided by SnapEDA
Some schematic symbols from Sparkfun

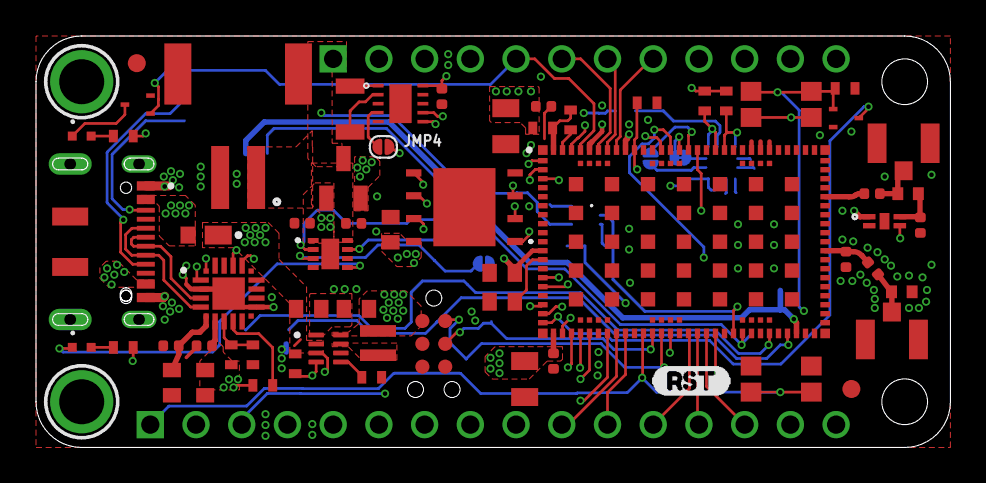
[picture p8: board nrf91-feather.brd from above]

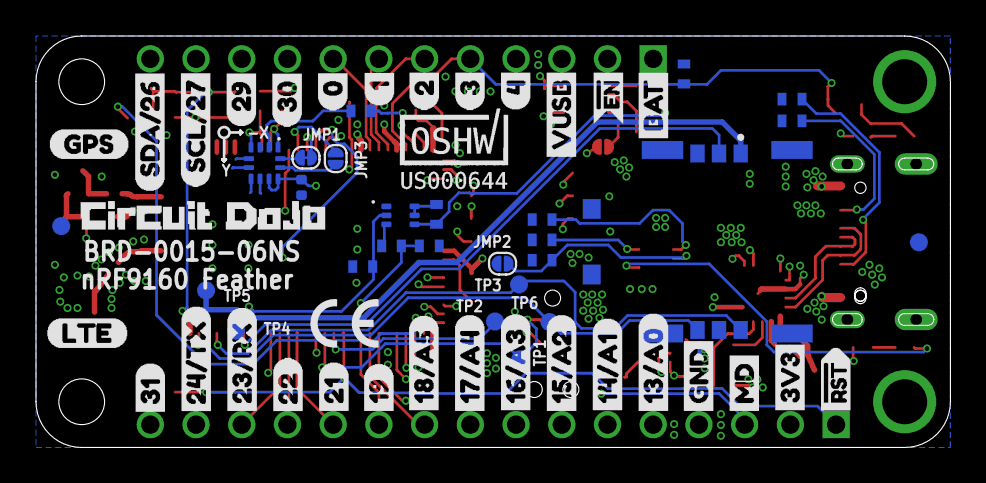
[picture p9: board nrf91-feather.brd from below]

Board: 4 copper layers, 50.8 x 22.9 mm, 128 parts (59 on the bottom side), 79 nets.

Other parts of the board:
U$1: 13#A00
U$2: LOGO-CIRCUITDOJO
U$5: A3L-LOC
U$6: LOGO-OSHWA
U$7: LOGO-CE
U$8: 290
U$9: BAT0
U$10: 20
U$11: 30
U$12: 310
U$13: 00
U$14: MD0
U$15: #RST0
U$16: 24#TX0
U$17: 23#RX0
U$18: 220
U$19: 210
U$20: 190
U$21: GPS0
U$22: LTE0
U$23: RST0
U$24: 10
U$25: #EN0
U$26: SCL#270
U$27: SDA#260
U$28: 300
U$39: 14#A10
U$40: 15#A20
U$41: 16#A30
U$42: 17#A40
U$43: 18#A50
U$69: GND12
U$71: 3V314
U$73: VUSB25
U$89: 412

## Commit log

2020-04-29 First commit. This board went to fab.
    [nrf91-feather.brd, nrf91-feather.sch]
2020-04-29 Adding parallel LDO for low power op. (without need to shut everything off)
    [nrf91-feather.brd, nrf91-feather.sch]
2020-05-05 Current tweaks
    [nrf91-feather.brd, nrf91-feather.sch]
2020-05-07 Removing LDO. Cleaning up traces. Fixing slot issue! Adding timer back.
    [nrf91-feather.brd, nrf91-feather.sch]
2020-05-07 1. Add doc outline 2. Adding tdocu 3. Exporting assembly docs using cam2print PDF 4. Updating nRF91 footprint
    [nrf91-feather.brd, nrf91-feather.sch]
2020-05-11 1. Clean up silk 2. Updated 3D packages 3. Pushed to OSH Park + Fusion 4. Added 1.8V LDO for LNA
    Proto2
    [nrf91-feather.brd, nrf91-feather.sch]
2020-05-20 1. Changing name of design to nRF9160 Feather 2. Fixing holes with BOM export.
    [nrf91-feather.brd, nrf91-feather.sch]
2020-05-26 1. Adding pulldown on EN pin
    [nrf91-feather.brd, nrf91-feather.sch]
2020-06-08 Using internal switch to route GPS signal.
    [nrf91-feather.brd, nrf91-feather.sch]
2020-06-08 Circuitry for external active GPS antenna.
    [nrf91-feather.brd, nrf91-feather.sch]
2020-06-30 Replacing some parts that are not available. Renaming MOSI to COPI, MISO to CIPO
    [nrf91-feather.brd, nrf91-feather.sch]
2020-07-03 Test points for SWD. Adding indent and removing solder pads from underneath the USB connector. Connecting un-connected ground connections Re-arranging bypass/GPS circuit
    [nrf91-feather.brd, nrf91-feather.sch]
2020-07-17 Adding OSHW logo with project #.
    [nrf91-feather.brd, nrf91-feather.sch]
2020-07-18 Replacing 47u with JMK212BJ476MG-T Replacing 56pf with CC0402GRNPO9BN560 Replace 4.7u with JMK107BB7475MA-T
    [nrf91-feather.brd, nrf91-feather.sch]
2020-07-26 Adding PDF schematic.
2020-07-31 Fixing silkscreen for a few components.
    [nrf91-feather.brd, nrf91-feather.sch]
2020-08-27 Adding CE marking
    [nrf91-feather.brd]
2020-09-23 V2 edits.
    * Replace battery measurement load switch
    * Fix footprint for LEDs
    [nrf91-feather.brd, nrf91-feather.sch]
2020-10-19 Adding LIS2DH12TR Changing mode pin to be post switch, pre-GPIO Adding more clear pins labels. (Thanks to Sparkfun Buzzard - https://sparkfunx.github.io/Buzzard/)
    [nrf91-feather.brd, nrf91-feather.sch]
2020-10-27 Adding jumper for "permanent on" if the end user wants it.
    [nrf91-feather.brd, nrf91-feather.sch]
2020-10-30 Fixing orientation of XY label
    [nrf91-feather.brd]
2020-12-02 Fixing SDA/SCL labels
    [nrf91-feather.brd]
2020-12-07 Updating LIS2DH footprint for assembly drawing.
    [nrf91-feather.brd, nrf91-feather.sch]
2022-04-14 Updating documentation to v4
    Changed:
    * v4 brd and sch
    * Updated schematic pdf
    [nrf91-feather.brd, nrf91-feather.sch]
2022-10-24 Update to Version 5
    * No longer supports complete shutdown mode
    * Using nRF9160 B1A variant
    * Now supports "buttonless" DFU mode
    * Now supports direct USB-C connection
    Added:
    * Ferrite and 47u for power inputs
    * Additional bypass to match nRF9160 reference
    * Relocated CP2102 closer to USB connector
    * Improved ground return paths
    * Pins reference nRF9160 pin numbers
    * Changed 47uf cap to 4.7u for B1 variant
    * Replaced Buck with TPS62840
    * Added jumper for disabling charger
    * Added current resistors for CC pins
    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
    [nrf91-feather.brd, nrf91-feather.sch]
2023-09-05 Fixed Iq issues when Vbat > 3.8V
    Connected RTC directly to 3.3V
    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
    [nrf91-feather.brd, nrf91-feather.sch]
2024-01-29 Addressing issue with paste mask on U8
    [nrf91-feather.brd, nrf91-feather.sch]
2024-05-22 Pushing v6 files.
    [nrf91-feather.brd, nrf91-feather.sch]

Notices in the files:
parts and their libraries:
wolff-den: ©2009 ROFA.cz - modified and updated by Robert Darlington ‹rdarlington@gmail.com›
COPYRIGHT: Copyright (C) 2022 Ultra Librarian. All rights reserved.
